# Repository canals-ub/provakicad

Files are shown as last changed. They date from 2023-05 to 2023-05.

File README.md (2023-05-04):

# Disseny Placa Pr&#224;ctica 5

>**Autors:** J.L. Soler, J. Canals, J.D. Prades, M. L&#243;pez

>**Versi&#243; Curs 2022/2023**

----------

## Objectiu

>PCB per practicar la soldadura de diferents tipus de components, i el test i verificaci&#243; de muntatges.

## Requisits / Especificacions

* Alimentaci&#243; 12V, regulada 5V

* Microcontrolador PIC18

* Polsadors (2x)

* Indicadors LED (2x)

* Comunicacions CAN

* Driver motor

* Sensor humitat-temperatura

* Interfície d'expansió MIKROE

## Components

| Descripci&#243; | Ref | Package |Datasheet | Prove&#239;dor | Preu | Unitats |
| --- | --- | --- | --- | ---| --- | --- |
| Microcontrolador | PIC18F26Q83-I/SS | SOIC-28 |[datasheet](https://www.mouser.es/datasheet/2/268/PIC18F27_47_57Q83_Preliminary_Data_Sheet_40002265B-2887591.pdf) | [Mouser](https://www.mouser.es/c/?q=PIC18F27Q83-I%2FSO)| 2,17&euro;| 1x |
| XTAL-Ressonador | CSTCR7M99G53-R0 | SMD |[Datasheet](https://www.mouser.es/datasheet/2/281/p16e-522700.pdf) | [Mouser](https://www.mouser.es/ProductDetail/Murata-Electronics/CSTCR7M99G53-R0?qs=Zd9RUO93%2Fo7cnwzsujIkpA%3D%3D)  | 0,27&euro; | 1x |
| CAN | MCP2551-I-SN | SOIC-8 |[Datasheet](http://ww1.microchip.com/downloads/en/devicedoc/21667d.pdf) | [Mouser](https://www.mouser.es/ProductDetail/Microchip-Technology/MCP2551T-E-SN?qs=gZwDaUDMhIcQtLtB%252B7bOWQ%3D%3D) | 1,57&euro; | 1x |
| Regulador LDO | LM317KTTR | TO-263-3| [Datasheet](https://www.ti.com/general/docs/suppproductinfo.tsp?distId=26&gotoUrl=https://www.ti.com/lit/gpn/lm317) | [Mouser](https://www.mouser.es/ProductDetail/Texas-Instruments/LM317KTTR?qs=iSMark9AYDU6ASyyp8LD6g%3D%3D) | 0,74&euro; | 1x |
| Ferrita | BLM15AX100SND | SMD 0402 | [Datasheet](https://eu.mouser.com/datasheet/2/281/ENFA0018-1915754.pdf) | [Mouser](https://eu.mouser.com/ProductDetail/Murata-Electronics/BLM15AX601SN1D?qs=MY6wChARw2zrjX4xpWbUQA%3D%3D) |  0,94&euro; | 1x |
| Sensor RH-Temp | SHT1x | | [Datasheet](https://www.sparkfun.com/datasheets/Sensors/SHT1x_datasheet.pdf) | []() | | 1x |
| Rel&#233; | SR5-12V-200-1C  |- |[Datasheet](https://www.mouser.es/datasheet/2/670/sr5-2950657.pdf) | [Mouser](https://www.mouser.es/ProductDetail/CUI-Devices/SR5-12V-200-1C?qs=4ASt3YYao0WMNY1cu6cO0A%3D%3D)  | 1,17&euro; | 1x |
| Transistor | BC817-25-QR | SOT-23-3 | [Datasheet](https://www.mouser.es/datasheet/2/916/BC817_Q_SER-2498268.pdf) | [Mouser](https://www.mouser.es/ProductDetail/Nexperia/BC817-25-QR?qs=e8oIoAS2J1TYx6o1G4RDyg%3D%3D) | 0,16&euro; | 1x |
| Polsador | EVP-BT7A4A000 | SMD | [Datasheet](https://www.mouser.es/datasheet/2/315/sw_lt_eng_6s_th-2889044.pdf) | [Mouser](https://www.mouser.es/ProductDetail/Panasonic/EVP-BT7A4A000?qs=CiayqK2gdcK%2FK8JCTM%2FBCw%3D%3D) | 0,291&euro; | 3x |
| LED | 156120VS75000 green | SMD 1206 | [Datasheet](https://www.mouser.es/datasheet/2/445/156120VS75000-3085422.pdf) | [Mouser](https://www.mouser.es/ProductDetail/Wurth-Elektronik/156120VS75000?qs=2kOmHSv6VfQAUFg5BeuEfQ%3D%3D) | 0,188&euro; | 1x |
| LED | 156120RS75000 red |SMD 1206  |[Datasheet](https://www.mouser.es/datasheet/2/445/156120RS75000-3085670.pdf) | [Mouser](https://www.mouser.es/ProductDetail/Wurth-Elektronik/156120RS75000?qs=2kOmHSv6VfTlw4DhG%252BTIQw%3D%3D) | 0,188&euro; | 1x |
| Diode LDO | 1N4002T | THT axial |[Datasheet](https://www.diodes.com/assets/Datasheets/ds28002.pdf) | [Mouser](https://www.mouser.es/ProductDetail/Diodes-Incorporated/1N4002-T?qs=rGAXPo9uwV21tVJRR%252BhxrQ%3D%3D) | 0,169&euro; | 3x |
| Diode transil | SMAJ15A-TR | SMD/SMT|[Datasheet](https://www.mouser.es/datasheet/2/389/smaj10ca-2956135.pdf) | [Mouser](https://www.mouser.es/ProductDetail/STMicroelectronics/SMAJ15A-TR?qs=fMNaVbI0QcP5ezTdgkCxZA%3D%3D) | 0,404&euro; | 1x |
| Capacitat 100nF | C0805C104M5RACTU | SMD 0805 |[Datasheet](https://www.mouser.es/datasheet/2/212/KEM_C1002_X7R_SMD-1102033.pdf) | [Mouser](https://www.mouser.es/ProductDetail/KEMET/C0805C104M5RACTU?qs=VOOUd%252Bza08qHu13WgNByHQ%3D%3D) | 0,022&euro; | 6x |
| Capacitat 10uF | MCASE32NSB5106MTNA01 | SMD 1210 |[Datasheet](https://www.mouser.es/datasheet/2/396/Taiyo_Yuden_1102023_MC_mlcc_all_e-3081584.pdf) | [Mouser](https://www.mouser.es/ProductDetail/TAIYO-YUDEN/MCASE32NSB5106MTNA01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) | 0,30&euro; | 1x |
| Capacitat 1uF | 860020672005 | THT Radial 5mm |[Datasheet](https://www.mouser.es/datasheet/2/445/860020672005-3099424.pdf) | [Mouser](https://www.mouser.es/ProductDetail/TAIYO-YUDEN/MCASE32NSB5106MTNA01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) | 0,084&euro; | 1x |
| Connectors | 10129378-910002BLF| tira pins poste 2.54 |[Datasheet](https://cdn.amphenol-cs.com/media/wysiwyg/files/documentation/datasheet/boardwiretoboard/bwb_econostik_254headers.pdf) | [Mouser](https://www.mouser.es/ProductDetail/Amphenol-FCI/10129378-910002BLF?qs=0lQeLiL1qyYh8zFHsKDebQ%3D%3D) |0,18&euro; | x19 |
| Resist&#232;ncies | diverses | SMD 1206 | |  | | 11x |

## Historial de canvis

| Data | Autor | Branch | Versi&#243; | Descripci&#243; |
| --- | --- | --- | --- | --- |
|  28/03/2023 | mlopez | Master | initial commit | Primera versi&#243; d'esquem&#224;tic i selecci&#243; de components |
|  30/03/2023 | dprades | P5 | v1 | Reselecci&#243; de components disponibles a mercat |
|  04/04/2023 | dprades | P5 | v2 | Esquem&#224;tic final i placement |
|  05/04/2023 | jcanals | P5 | v3 | Candidata a producci&#243; |
|  06/04/2023 | jcanals | P5 | v4 | Arreglat el Vadj del regulador.  |
|  20/04/2023 | dprades | P5 | v5 | Arreglats footprints uC, transil, switch i ferrita. |
|  20/04/2023 | dprades | P5 | v5.1 | Correccions menors format. |

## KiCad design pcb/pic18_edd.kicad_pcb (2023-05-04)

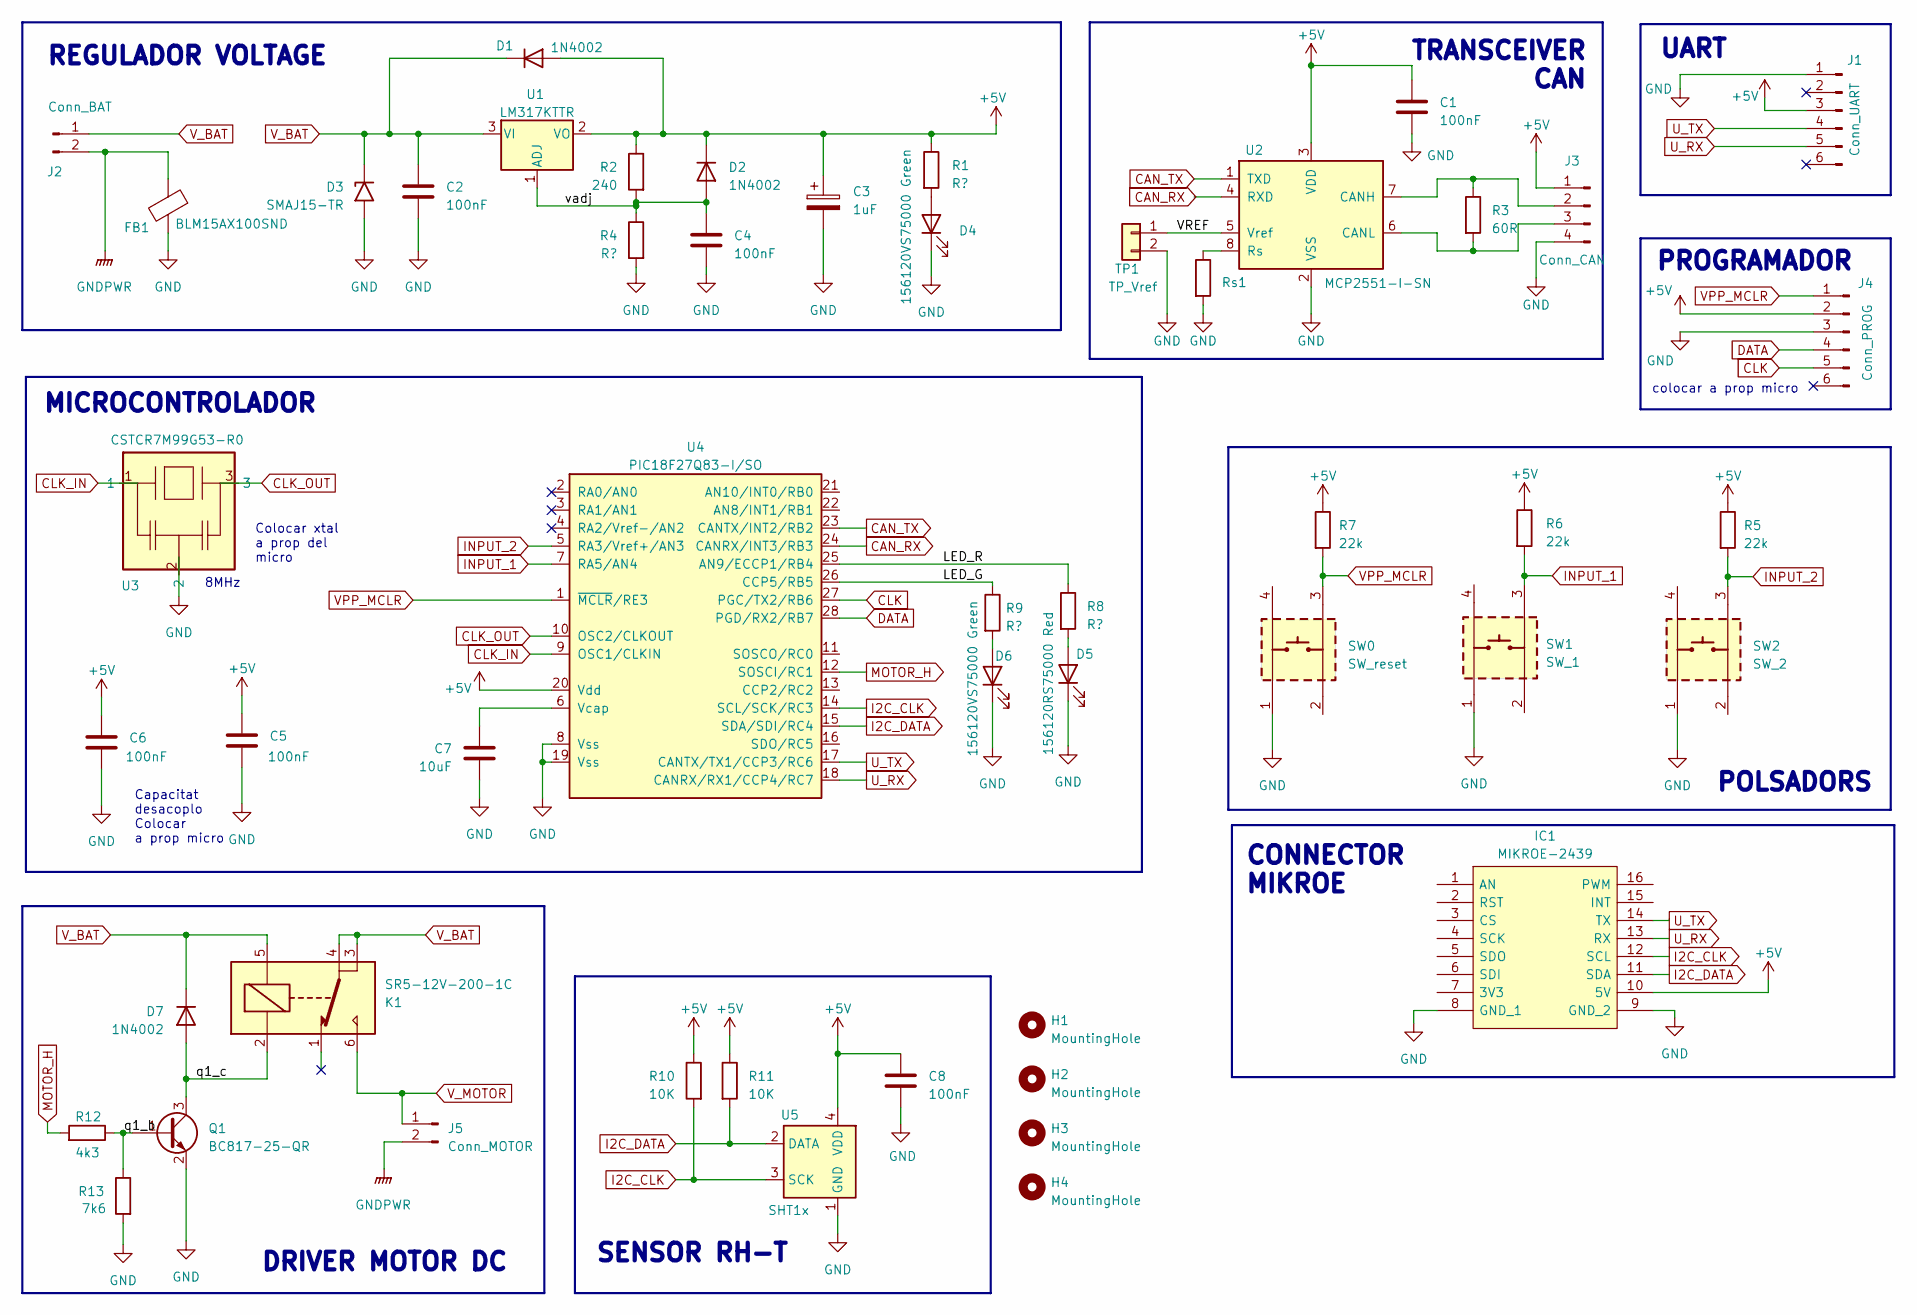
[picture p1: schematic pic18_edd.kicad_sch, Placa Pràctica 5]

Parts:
C1, C2, C4, C5, C6, C8: 100nF; C_1206_3216Metric
C3: 1uF; CP_Radial_D5.0mm_P2.00mm
C7: 10uF; C_1210_3225Metric_Pad1.33x2.70mm_HandSolder
D1, D2, D7: 1N4002; D_DO-41_SOD81_P10.16mm_Horizontal
D3: SMAJ15-TR; D_SMA_Handsoldering
D4, D6: 156120VS75000 Green; LED_1206_3216Metric_Pad1.42x1.75mm_HandSolder
D5: 156120RS75000 Red; LED_1206_3216Metric_Pad1.42x1.75mm_HandSolder
FB1: BLM15AX100SND; L_0402_1005Metric_Pad0.77x0.64mm_HandSolder
H1, H2, H3, H4: MountingHole; MountingHole_3.2mm_M3
IC1: MIKROE-2439; mikroe_s; Manufacturer_Part_Number MIKROE-2439; Mouser Part Number 932-MIKROE-2439
J1: Conn_UART; PinSocket_1x06_P2.54mm_Vertical
J2: Conn_BAT; PinSocket_1x02_P2.54mm_Vertical
J3: Conn_CAN; PinSocket_1x04_P2.54mm_Vertical
J4: Conn_PROG; PinSocket_1x06_P2.54mm_Vertical
J5: Conn_MOTOR; PinSocket_1x02_P2.54mm_Vertical
K1: SR5-12V-200-1C; DIP-6_300_ELL
Q1: BC817-25-QR; SOT-23
R1, R4, R8, R9: R?; R_1206_3216Metric_Pad1.30x1.75mm_HandSolder
R2: 240; R_1206_3216Metric_Pad1.30x1.75mm_HandSolder
R3: 60R; R_1206_3216Metric_Pad1.30x1.75mm_HandSolder
R5, R6, R7: 22k; R_1206_3216Metric_Pad1.30x1.75mm_HandSolder
R10, R11: 10K; R_1206_3216Metric_Pad1.30x1.75mm_HandSolder
R12: 4k3; R_1206_3216Metric_Pad1.30x1.75mm_HandSolder
R13: 7k6; R_1206_3216Metric_Pad1.30x1.75mm_HandSolder
Rs1: R_1206_3216Metric_Pad1.30x1.75mm_HandSolder
SW0: SW_reset; Push_btn_SMD_sqr_handsoldering
SW1: SW_1; Push_btn_SMD_sqr_handsoldering
SW2: SW_2; Push_btn_SMD_sqr_handsoldering
TP1: TP_Vref; PinSocket_1x02_P2.54mm_Vertical
U1: LM317KTTR; TO-263-3_TabPin2
U2: MCP2551-I-SN; SOIC-8_3.9x4.9mm_P1.27mm
U3: CSTCR7M99G53-R0; SMD_XTAL
U4: PIC18F27Q83-I/SO; SOIC-28W_7.5x18.7mm_P1.27mm
U5: SHT1x

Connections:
+5V: C1.1, C3.1, C5.1, C6.1, C8.1, D1.2 (A), D2.1 (K), IC1.10 (5V), J1.3, J3.1, J4.2, R1.1, R2.1, R5.1, R6.1, R7.1, R10.1, R11.1, U1.2 (VO), U2.3 (VDD), U4.20 (Vdd), U5.4 (VDD)
/LED_G: R9.1, U4.26 (CCP5/RB5)
/LED_R: R8.1, U4.25 (AN9/ECCP1/RB4)
/VREF: TP1.1, U2.5 (Vref)
/q1_b: Q1.1 (B), R12.1, R13.1
/q1_c: D7.2 (A), K1.2, Q1.3 (C)
/vadj: C4.1, D2.2 (A), R2.2, R4.1, U1.1 (ADJ)
CAN_RX: U2.4 (RXD), U4.24 (CANRX/INT3/RB3)
CAN_TX: U2.1 (TXD), U4.23 (CANTX/INT2/RB2)
CLK: J4.5, U4.27 (PGC/TX2/RB6)
CLK_IN: U3.1, U4.9 (OSC1/CLKIN)
CLK_OUT: U3.3, U4.10 (OSC2/CLKOUT)
DATA: J4.4, U4.28 (PGD/RX2/RB7)
GND: C1.2, C2.2, C3.2, C4.2, C5.2, C6.2, C7.2, C8.2, D3.2 (A2), D4.1 (K), D5.1 (K), D6.1 (K), FB1.2, IC1.8 (GND_1), IC1.9 (GND_2), J1.1, J3.4, J4.3, Q1.2 (E), R4.2, R13.2, Rs1.2, SW0.1, SW1.1, SW2.1, TP1.2, U2.2 (VSS), U3.2, U4.8 (Vss), U4.19 (Vss), U5.1 (GND)
GNDPWR: FB1.1, J2.2, J5.2
I2C_CLK: IC1.12 (SCL), R10.2, U4.14 (SCL/SCK/RC3), U5.3 (SCK)
I2C_DATA: IC1.11 (SDA), R11.2, U4.15 (SDA/SDI/RC4), U5.2 (DATA)
INPUT_1: R6.2, SW1.3, U4.7 (RA5/AN4)
INPUT_2: R5.2, SW2.3, U4.5 (RA3/Vref+/AN3)
MOTOR_H: R12.2, U4.12 (SOSCI/RC1)
unnamed: D4.2 (A), R1.2
unnamed: D5.2 (A), R8.2
unnamed: D6.2 (A), R9.2
unnamed: J3.2, R3.1, U2.7 (CANH)
unnamed: J3.3, R3.2, U2.6 (CANL)
unnamed: Rs1.1, U2.8 (Rs)
unnamed: C7.1, U4.6 (Vcap)
U_RX: IC1.13 (RX), J1.5, U4.18 (CANRX/RX1/CCP4/RC7)
U_TX: IC1.14 (TX), J1.4, U4.17 (CANTX/TX1/CCP3/RC6)
VPP_MCLR: J4.1, R7.2, SW0.3, U4.1 (~MCLR/RE3)
V_BAT: C2.1, D1.1 (K), D3.1 (A1), D7.1 (K), J2.1, K1.3, K1.4, K1.5, U1.3 (VI)
V_MOTOR: J5.1, K1.6

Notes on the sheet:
PROGRAMADOR
Colocar xtal a prop del micro
DRIVER MOTOR DC
CONNECTOR MIKROE
TRANSCEIVER CAN
8MHz
REGULADOR VOLTAGE
MICROCONTROLADOR
SENSOR RH-T
UART
colocar a prop micro
POLSADORS
Capacitat desacoplo Colocar a prop micro

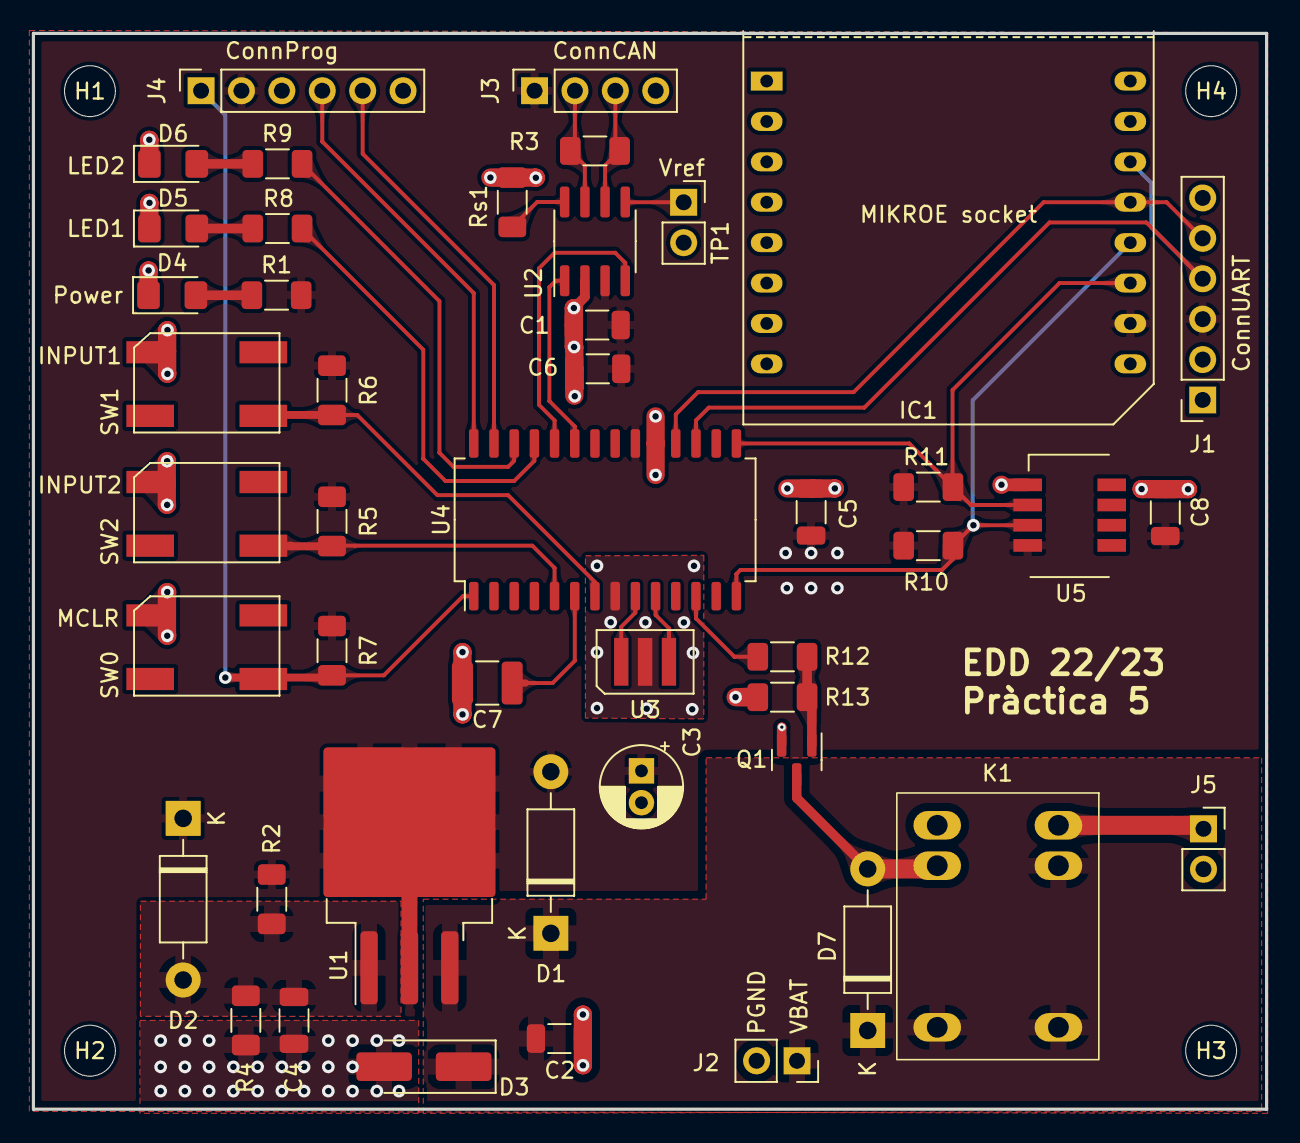
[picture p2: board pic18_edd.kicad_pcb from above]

Board: 2 copper layers, 77.5 x 67.6 mm, 51 parts (1 on the bottom side), 32 nets.

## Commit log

2023-04-21 all in
    [pic18_edd.kicad_pcb, pic18_edd.kicad_sch]
2023-04-21 pcb folder
    [pic18_edd.kicad_pcb, pic18_edd.kicad_sch]
2023-05-04 last version
    [pic18_edd.kicad_pcb, pic18_edd.kicad_sch]
